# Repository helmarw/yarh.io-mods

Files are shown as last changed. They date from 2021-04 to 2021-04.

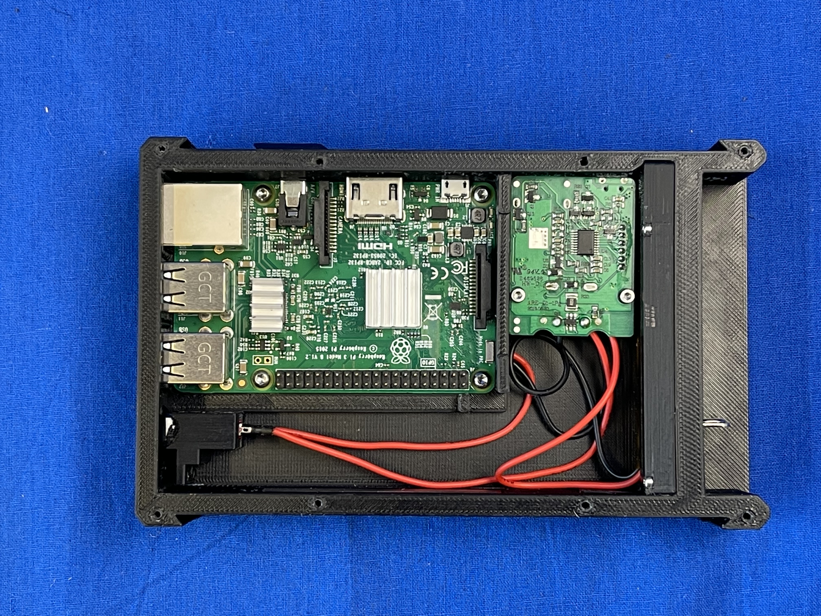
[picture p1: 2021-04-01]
Pictures/IMG_6975.jpg

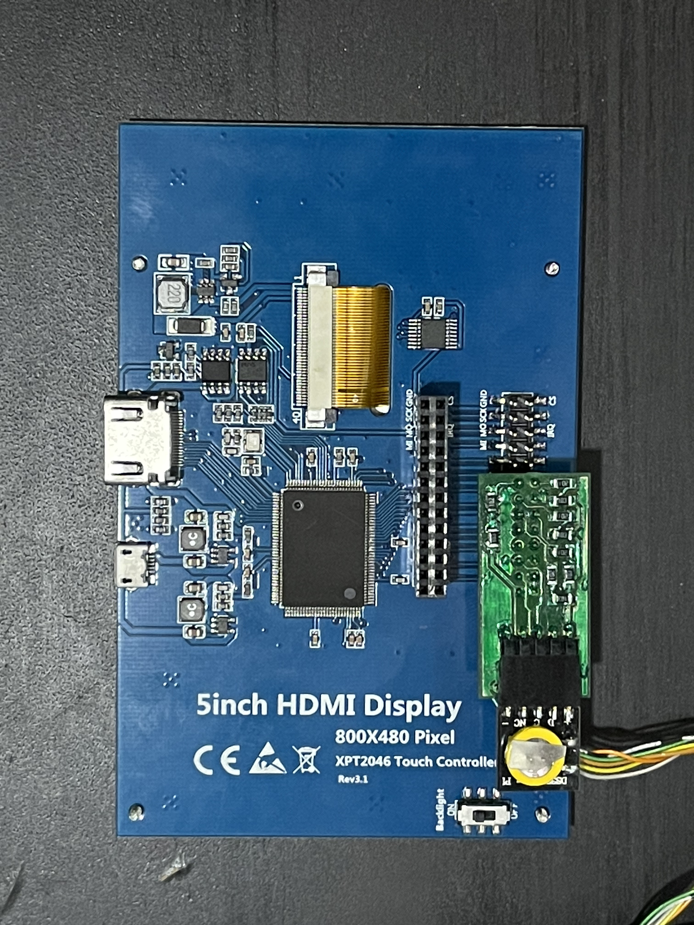
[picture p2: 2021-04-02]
Pictures/IMG_6980.jpg

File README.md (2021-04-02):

# yarh.io-mods
MODs for
[Y]ET [A]NOTHER [R]ASPBERRY [H]ANDHELD

original idea and files can be found here

https://yarh.io/yarh-io-mki.html

Assembly

Assembly_front

i added 5 programable GPIO buttons to the front and a custom made pcb (see kicad files) 
to connect the buttons and the RTC (or any other i2c device for that matter).
It can be hooked up to the free pinheader at the back of the LCD...

i uploded modified stl files for the frontpanel.
i also closed a few holes i didnt utilize and simplified the cabeling for my purpose.
Made a battery cover with place to store the stylus and
added a holder for a PureThermal2-UVC FLIR-camera to the housing.

The additional parts i used:

Prototype PCBs:

AZDelivery Set 16 x PCB Board
AZ-Delivery Vertriebs GmbH
https://www.amazon.de/dp/B078HV79XX/ref=cm_sw_em_r_mt_dp_2RHM7PPPENVQ2NX6XCZS?_encoding=UTF8&psc=1
or
ELEGOO Prototyp-Kit for DIY
ELEGOO Official US
https://www.amazon.com/dp/B072Z7Y19F/ref=cm_sw_em_r_mt_dp_VJY9EARDYE1PZMNZ06P7?_encoding=UTF8&psc=1

------------------------------------------------------------
Buttons:

YIXISI 180 pcs Button Micro Tactile Switch (4 pin 6x6mm 7x7mm)
YXS-DE
https://www.amazon.de/dp/B082ZL867J/ref=cm_sw_em_r_mt_dp_96NSV17K3W1S4MMYA5SG?_encoding=UTF8&psc=1
or
4 Pin Momentary Push Button Switch Sortiment Kit
BOJACK ELECTRON
Erfahren Sie mehr: https://www.amazon.com/dp/B07ZBHXBZ4/ref=cm_sw_em_r_mt_dp_M1YMZXK227A3NDJCXFJZ

------------------------------------------------------------

further information:

how to programm a shutdown button:
https://www.stderr.nl/Blog/Hardware/RaspberryPi/PowerButton.html

setting up gpio buttons via device tree overly (dtoverlay):
https://blog.gegg.us/2017/01/setting-up-a-gpio-button-keyboard-on-a-raspberry-pi/

howto use hwclock and delete fake-hwclock:
https://pimylifeup.com/raspberry-pi-rtc/

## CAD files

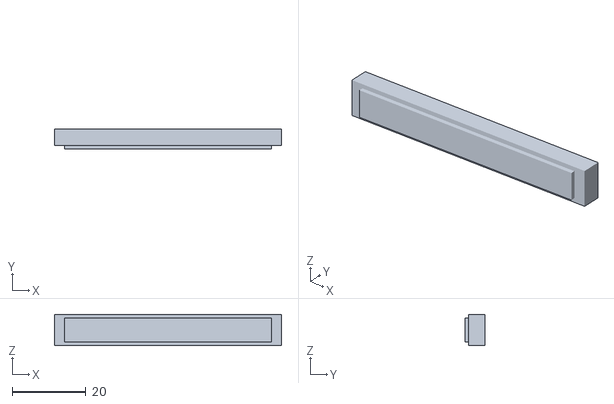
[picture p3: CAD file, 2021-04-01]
STL/seperate cover plugs/yarh-io-mki-main-body-cover-gpio.stl
61.5 x 5.50 x 8.50

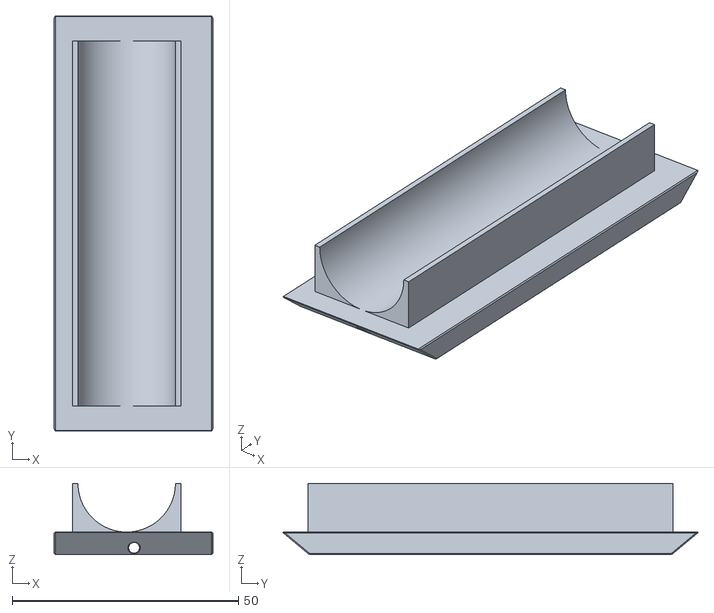
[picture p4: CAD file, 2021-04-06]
STL/yarh-io-mki-main-body-Battery-Cover.stl
35.0 x 91.6 x 15.8

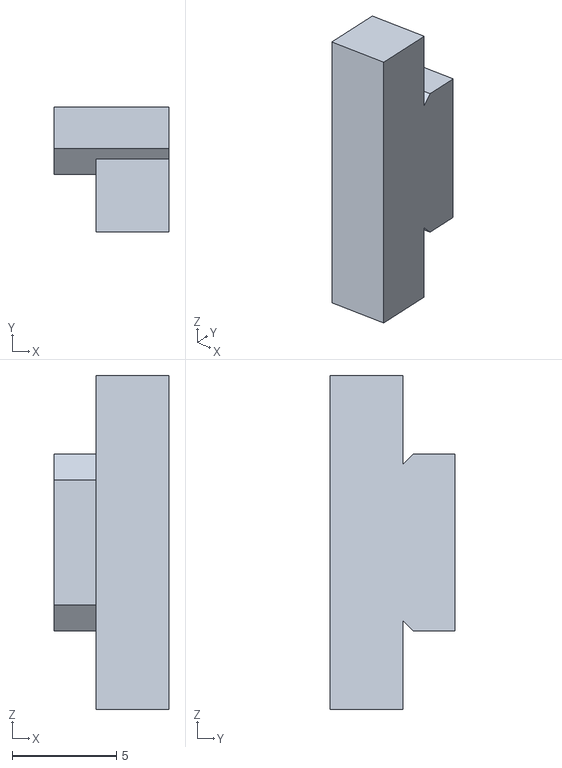
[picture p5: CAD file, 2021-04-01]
STL/seperate cover plugs/yarh-io-mki-main-body_cover_micro-usb.stl
5.50 x 6.00 x 16.0

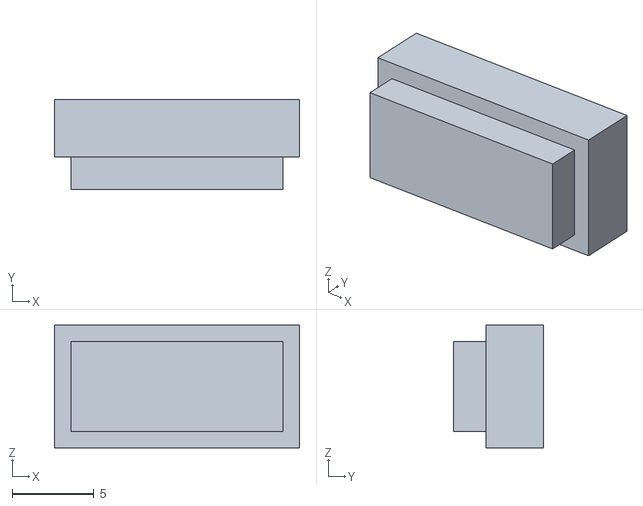
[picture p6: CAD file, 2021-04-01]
STL/seperate cover plugs/yarh-io-mki-main-body-cover-usb-a.stl
15.0 x 5.50 x 7.50

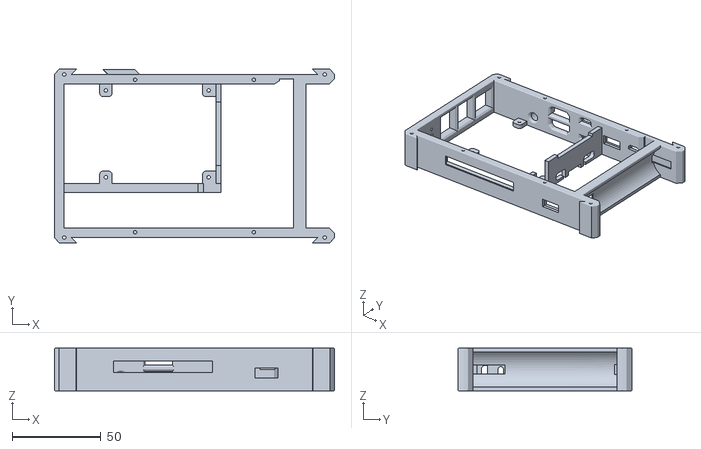
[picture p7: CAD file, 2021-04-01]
STL/yarh-io-mki-main-body-camera-holder-mod.stl
158.0 x 98.0 x 24.0

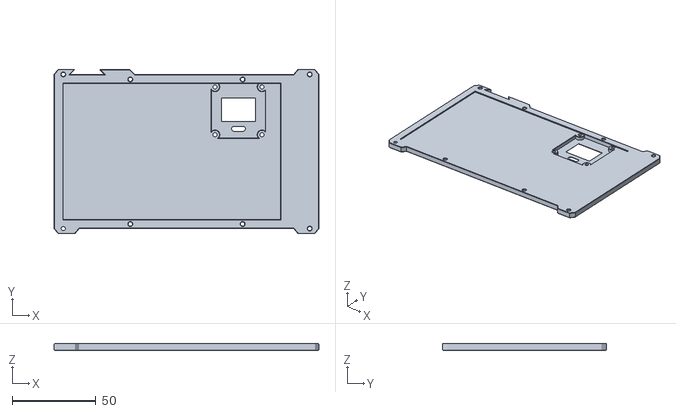
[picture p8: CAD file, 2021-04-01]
STL/yarh-io-mki-main-back-panel-camera-holder-mod.stl
158.0 x 98.0 x 4.00

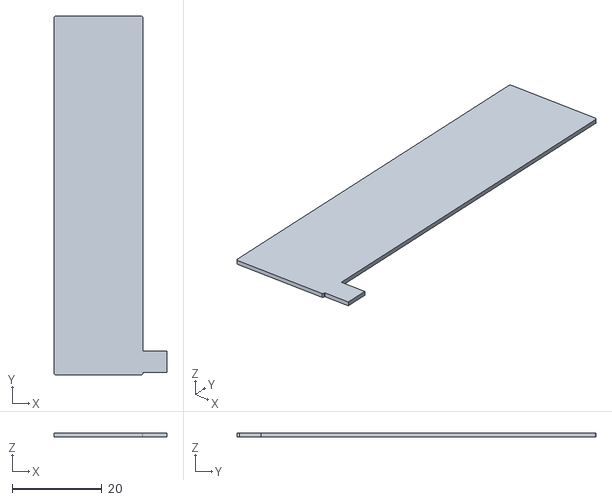
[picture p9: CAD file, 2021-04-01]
STL/yarh-io-mki-main-front-panel-7mm_with_buttons_-_Button_Cover.stl
25.2 x 79.8 x 0.8

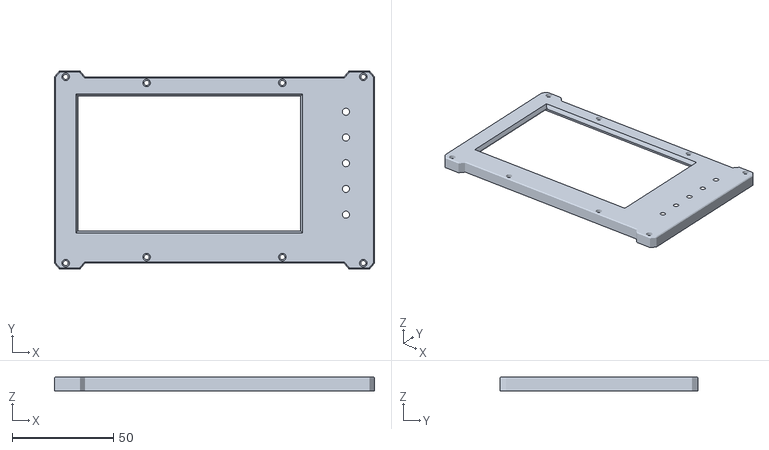
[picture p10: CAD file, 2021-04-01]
STL/yarh-io-mki-main-front-panel-7mm_with_buttons.stl
158.0 x 98.0 x 7.00

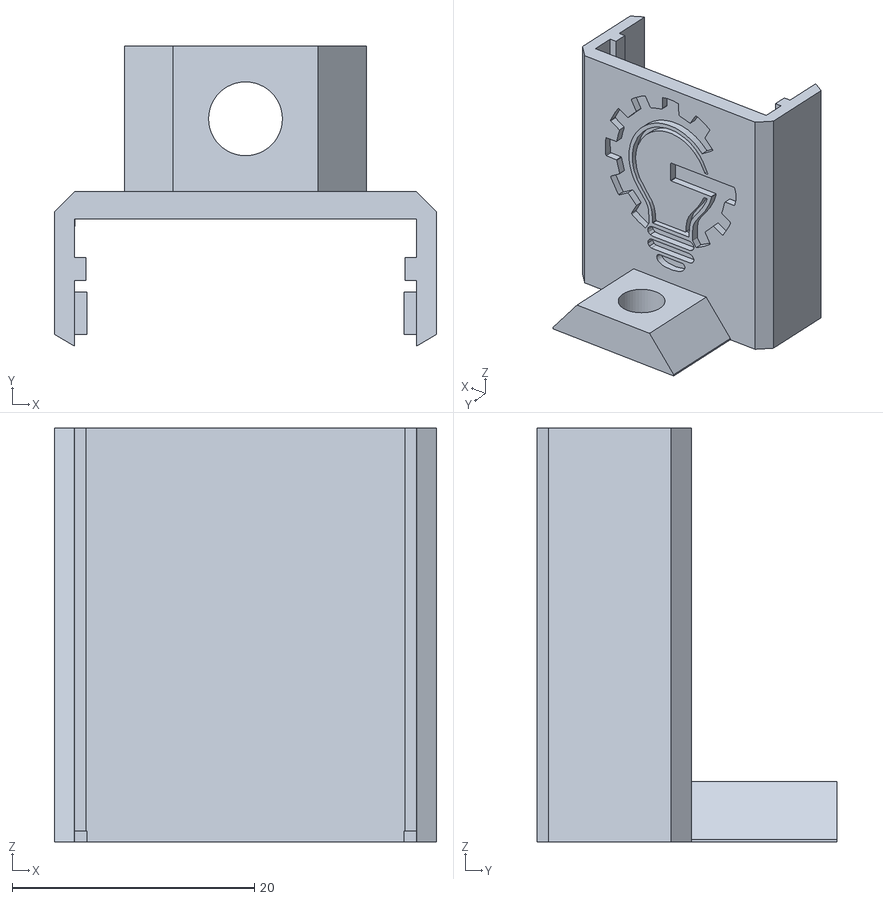
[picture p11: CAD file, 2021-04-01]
STL/PT2_mod/PT2 Case - Back 2.stl
31.6 x 24.8 x 34.2

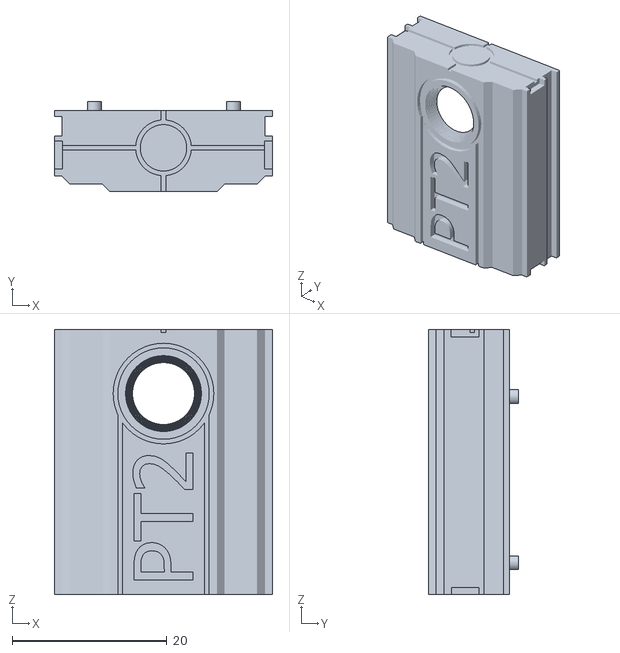
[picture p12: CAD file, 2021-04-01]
STL/PT2_mod/PT2 Case - Front 2.stl
28.2 x 11.7 x 34.2

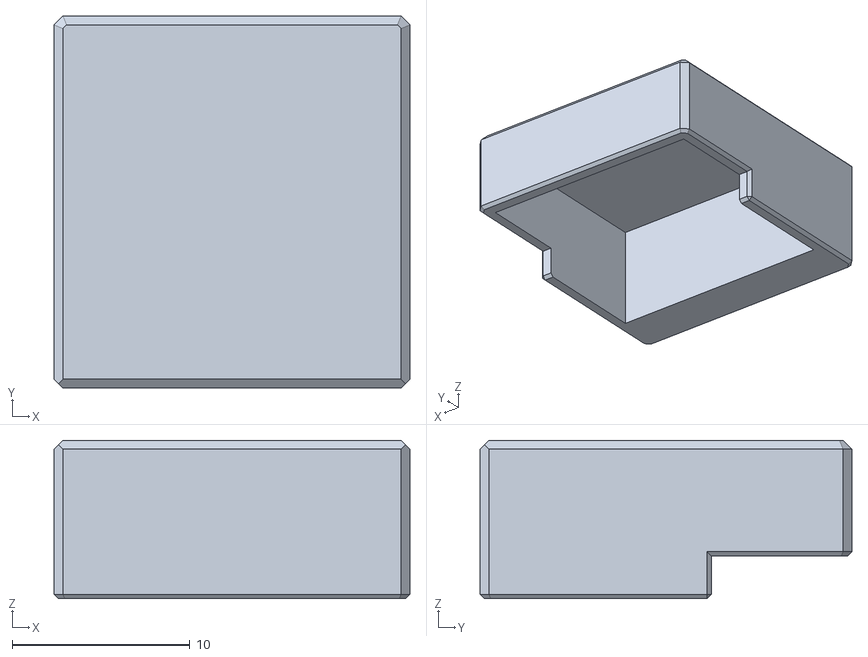
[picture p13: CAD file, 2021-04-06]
STL/yarh-io-mki-hdmi-connector-cover.stl
20.0 x 20.9 x 8.90

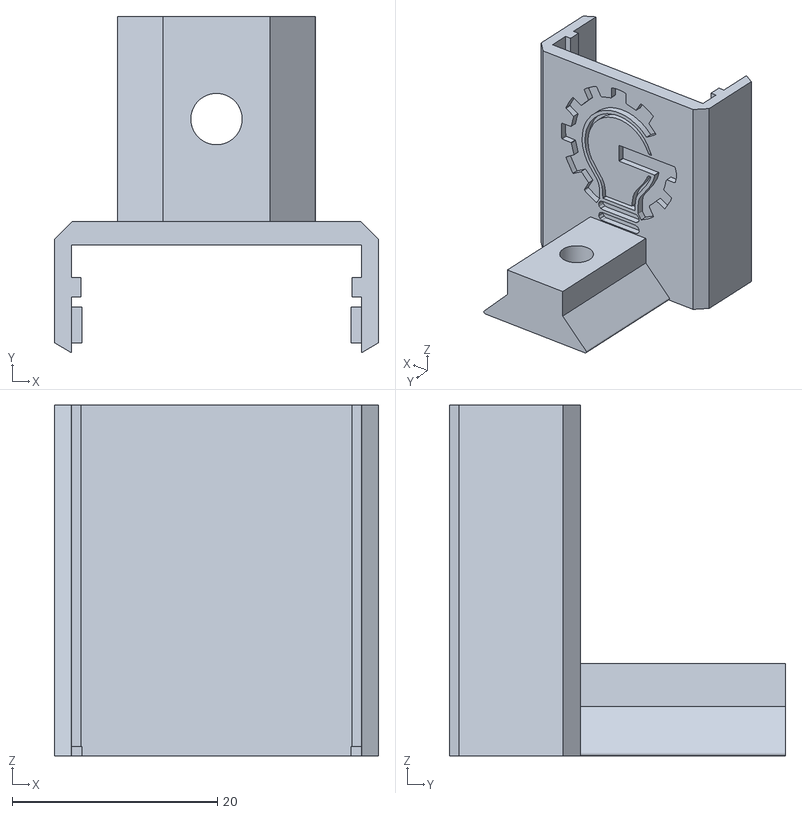
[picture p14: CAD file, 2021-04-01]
STL/PT2_mod/PT2 Case - Back 2 mod.stl
31.6 x 32.8 x 34.2

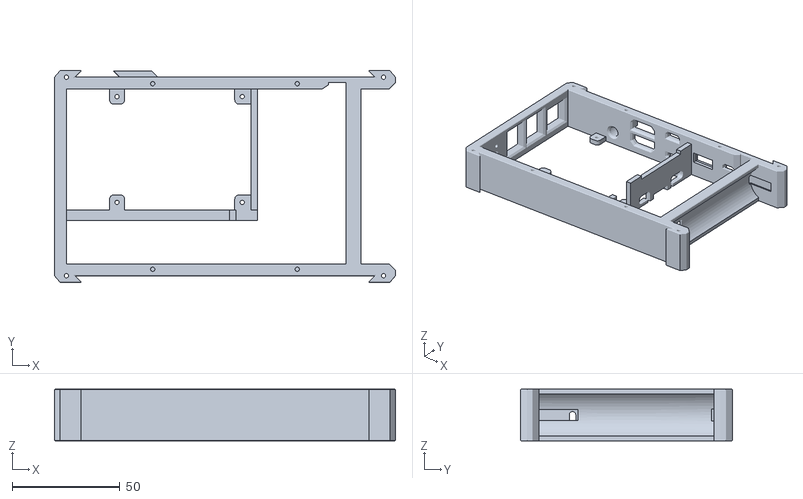
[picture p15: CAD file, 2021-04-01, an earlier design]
STL/yarh-io-mki-main-body_unused-ports-closed.stl
158.0 x 98.0 x 24.0

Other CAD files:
STL/yarh-io-mki-hdmi-connector-cover-mod.stl

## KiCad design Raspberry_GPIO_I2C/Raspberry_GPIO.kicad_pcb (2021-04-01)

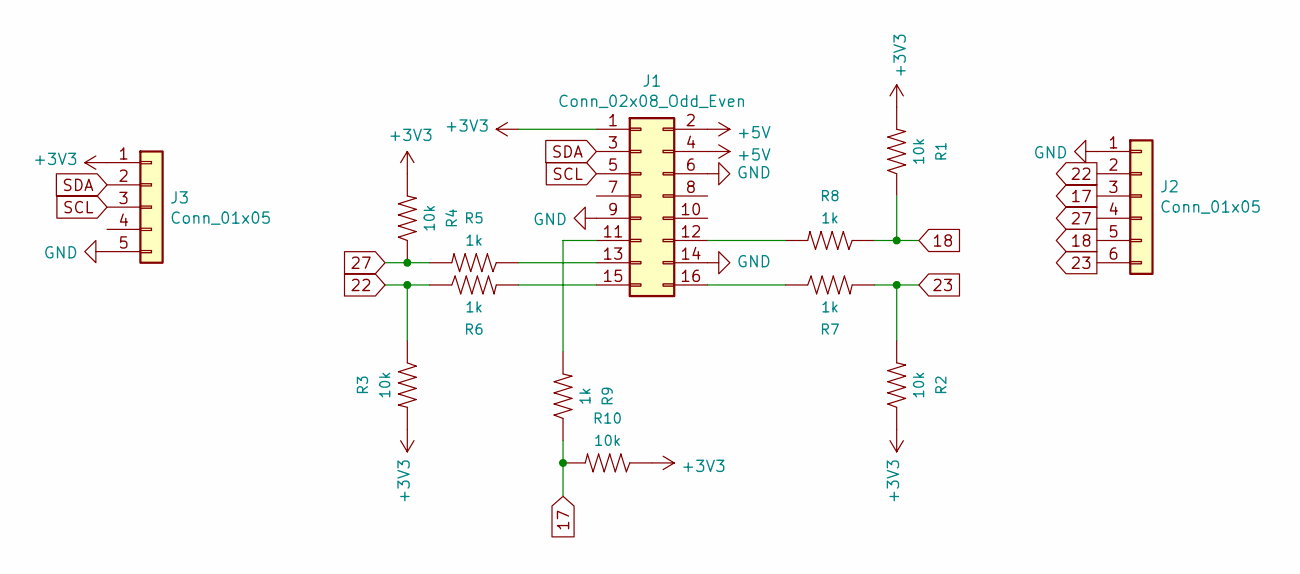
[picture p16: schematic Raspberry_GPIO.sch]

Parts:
J1: Conn_02x08_Odd_Even; PinSocket_2x08_P2.54mm_Vertical
J2: Conn_01x05; PinHeader_1x06_P2.54mm_Horizontal
J3: Conn_01x05; PinHeader_1x05_P2.54mm_Horizontal
R1, R2, R3, R4, R10: 10k; 1206
R5, R6, R7, R8, R9: 1k; 1206

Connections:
17: J2.3, R9.1, R10.2
18: J2.5, R1.1, R8.1
22: J2.2, R3.1, R6.1
23: J2.6, R2.2, R7.2
27: J2.4, R4.1, R5.2
+3V3: J1.1, J3.1, R1.2, R2.1, R3.2, R4.2, R10.1
+5V: J1.2, J1.4
GND: J1.6, J1.9, J1.14, J2.1, J3.5
unnamed: J1.11, R9.2
unnamed: J1.12, R8.2
unnamed: J1.13, R5.1
unnamed: J1.15, R6.2
unnamed: J1.16, R7.1
SCL: J1.5, J3.3
SDA: J1.3, J3.2

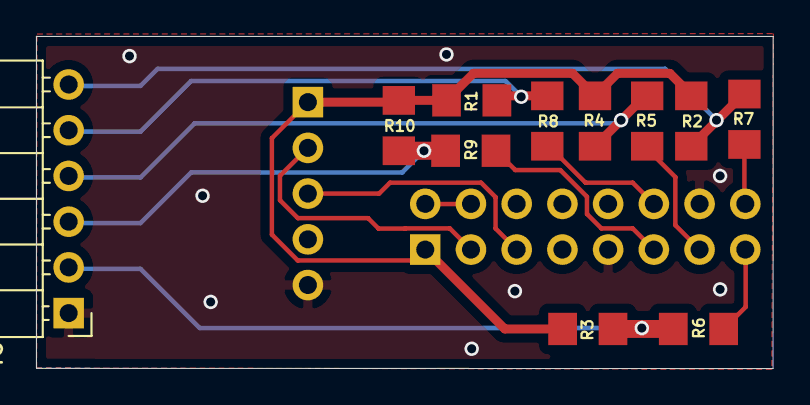
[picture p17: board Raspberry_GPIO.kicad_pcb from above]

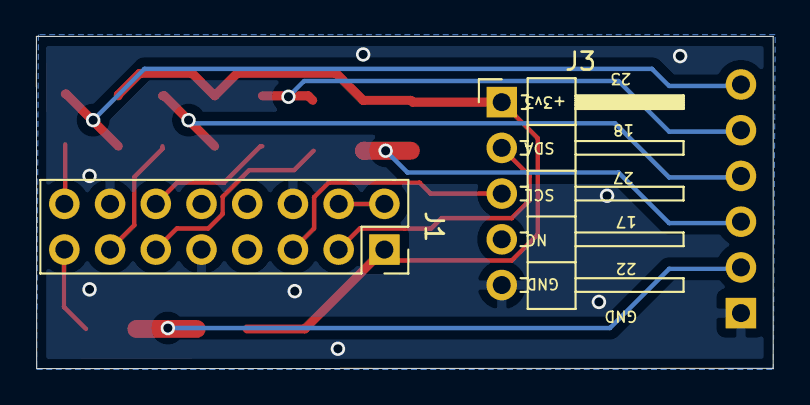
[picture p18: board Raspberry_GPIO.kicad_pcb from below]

Board: 2 copper layers, 40.9 x 18.5 mm, 13 parts (2 on the bottom side), 15 nets.

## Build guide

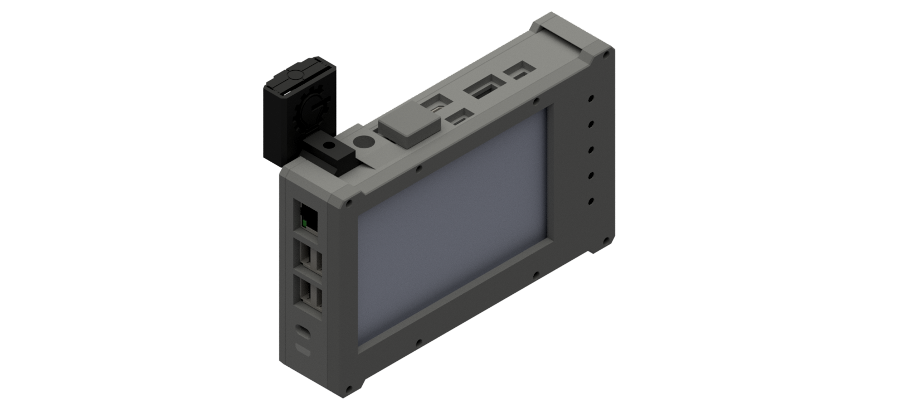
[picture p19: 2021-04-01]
Pictures/Assembly.png
